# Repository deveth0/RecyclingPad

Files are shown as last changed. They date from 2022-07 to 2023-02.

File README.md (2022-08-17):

# Recycling Pad

This repository contains all required files to build a `Recycling Pad` which is a plugin extension for the [Keygem Switch Tester](https://keygem.store/collections/switch-testers/products/switch-tester-3x3).

It features 3x3 keys, whereby any of the upper three once can be replaced by EC11 encoder(s).

## Gallery

[Fancy Images by @Xibaris](https://imgur.com/a/etkFRNU)

v0.1 revision Board
v0.1 revision PCB rear
v0.1 revision PCB front
v0.1 revision Side

## Required Parts

* 1x PCB
* 1x Pro Micro Controller
* 9x 1n4148 Diode (thru hole)
* 1x 6mm tactile switch (to reset MCU)
* up to 3 EC11 Encoders
* up to 9 Cherry-style mechanical switches
* up to 18 Millmax Sockets 3305 / 7305 (recommended, for hotswap)
* 4x 3.5mm Spacer (3d Print file available) => [Spacer 3.5mm](./Case/Recycling_Pad-Spacer_3,5mm.stl)
* 4x 6mm Spacer (3d Print file available) => [Spacer 6mm](./Case/Recycling_Pad-Spacer_9mm.stl)

Depending on your setup, you can replace any number of the upper switches with EC11 rotary encoders.

## Assembly

As the whole PCB is quite tight packed, you need to keep an eye on the soldering order. If you use Millmax Sockets, it's getting easier as you can remove the switches if required.

1. First solder in all the diodes and the reset switch
2. Then add the MillMax Sockets
3. Solder in the center EC11 encoder (if used)
3. Solder in the Pro Micro Headers (NOT THE Controler)
4. Solder in the the remaining EC11 Encoder (use plate as guide to keep the encoder aligned)
5. If not using Millmax: Add all switches to the plate and solder in the switches
5. Add the controller to the Headers

Depending on the length of your Headers, you might want to cut them after soldering. Otherwise they might touch the PCB and shortcircuit a switch.

## QMK

The `qmk` folder contains some base configurations for the Pad.

Note: rows and columns are switched, therefor your configuration needs to be rotated 90° (see example configs).

## Acknowledgements

Cherry Switch 3d Model: https://3dwarehouse.sketchup.com/model/81cf92a3e03098a5cc90be332989df6e/Key-switch-Cherry

Kicad Schematics / Footprints: https://github.com/imchipwood/dumbpad/tree/master/combo_oled

Schematics for embedded version: https://github.com/kb-elmo/QEZ

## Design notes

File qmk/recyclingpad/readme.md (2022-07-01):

# RecyclingPad

RecyclingPad 3x3 Macropad with up to three encoders

* Maintainer: [deveth0](https://github.com/deveth0)
* PCB repository: [dumbpad on github](https://github.com/deveth0/RecyclingPad)
  * PCB revisions:
    * v1.x - these revisions have two LEDs for layer indication
      * ['v1x'](v1x/): Default setup for single rotary encoder v0.x PCBs
      * ['v1x_left'](v1x_left/): Same as v1x but with rotary encoder on left side (use as blueprint for other positions)

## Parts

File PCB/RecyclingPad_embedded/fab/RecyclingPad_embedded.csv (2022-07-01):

Comment | Designator | Footprint | LCSC Part #
10uF | C1 | C_0805_2012Metric | C91245
22pF | C2,C3 | C_0805_2012Metric | C1804
0.1uF | C4,C5 | C_0805_2012Metric | C49678
1uF | C6 | C_0805_2012Metric | C28323
DIODEDO-1N4148 | D1,D2,D3,D4,D5,D6,D7,D8,D9 | D_SOD-323 | C2128
Polyfuse_Small | F1 | Fuse_1206_3216Metric | C69688
22 | R1,R2 | R_0805_2012Metric | C17561
10k | R3,R7 | R_0805_2012Metric | C17414
5.1k | R4,R5 | R_0805_2012Metric | C27834
CHERRY-MX-ENCODER | RE_0_1 | CHERRY-MX-ENCODER
CHERRY-MX-ENCODER | RE_3_1,RE_3_2 | CHERRY-MX-ENCODER
SW_Push | RESET1 | SW_SPST_TL3342 | C318884
MOMENTARY-SWITCH-SPST-LED-PTH-CHERRY | S1,S2,S3,S4,S5,S6 | CHERRY-MX
ATmega32U2-AU | U1 | TQFP-32_7x7mm_P0.8mm | C618733
SRV05-4 | U2 | SOT-23-6 | C85364
USB_C_Receptacle_USB2.0 | USB1 | USB_C_Receptacle_HRO_TYPE-C-31-M-12 | C165948
Crystal_GND24_Small | X1 | Crystal_SMD_3225-4Pin_3.2x2.5mm | C13738

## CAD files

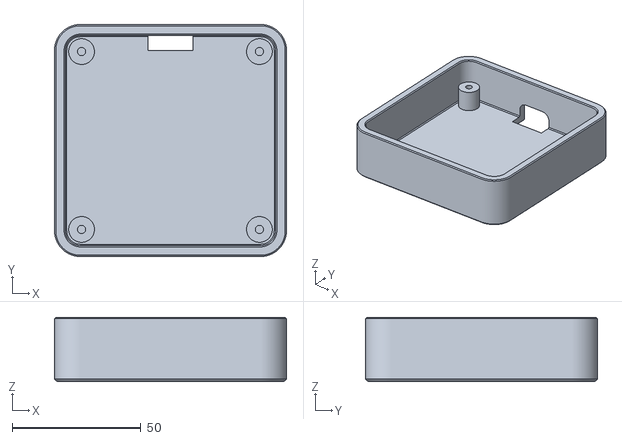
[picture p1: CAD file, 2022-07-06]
Case/Recycling_Pad-Case.stl
90.0 x 90.0 x 25.0

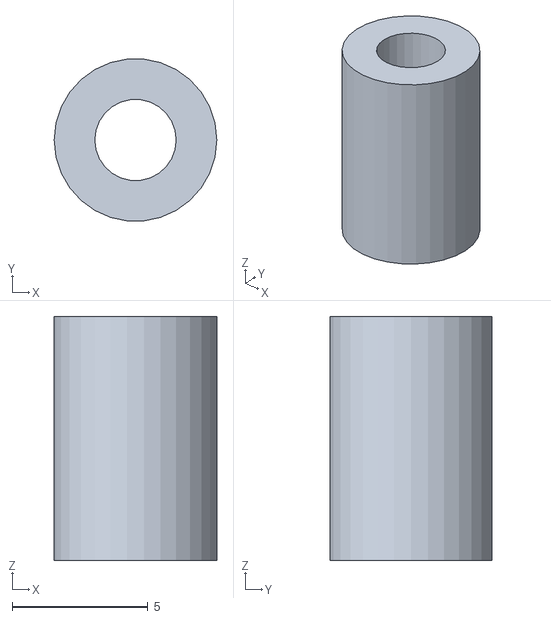
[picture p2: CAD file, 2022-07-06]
Case/Recycling_Pad-Spacer_9mm.stl
6.00 x 5.97 x 9.00

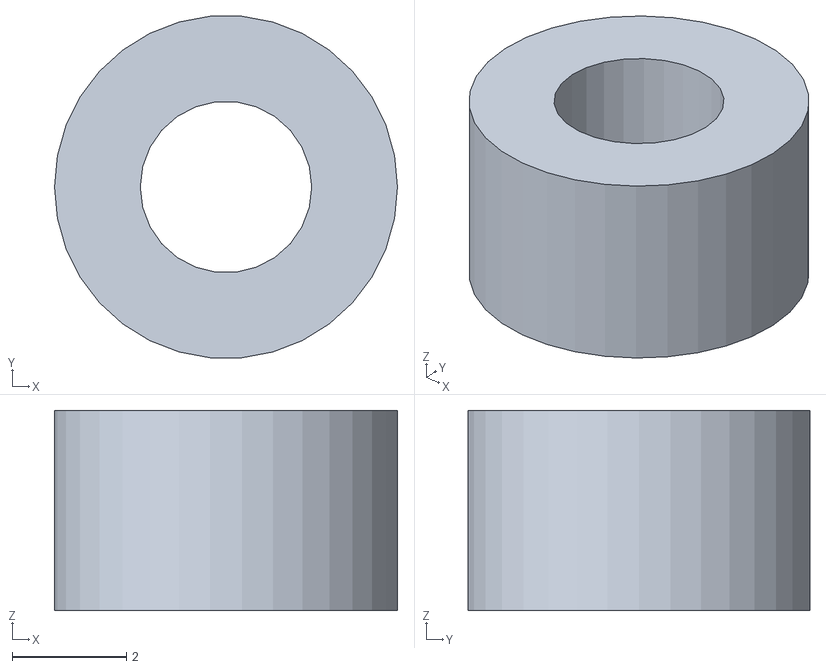
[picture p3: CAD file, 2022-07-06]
Case/Recycling_Pad-Spacer_3,5mm.stl
6.00 x 5.97 x 3.50

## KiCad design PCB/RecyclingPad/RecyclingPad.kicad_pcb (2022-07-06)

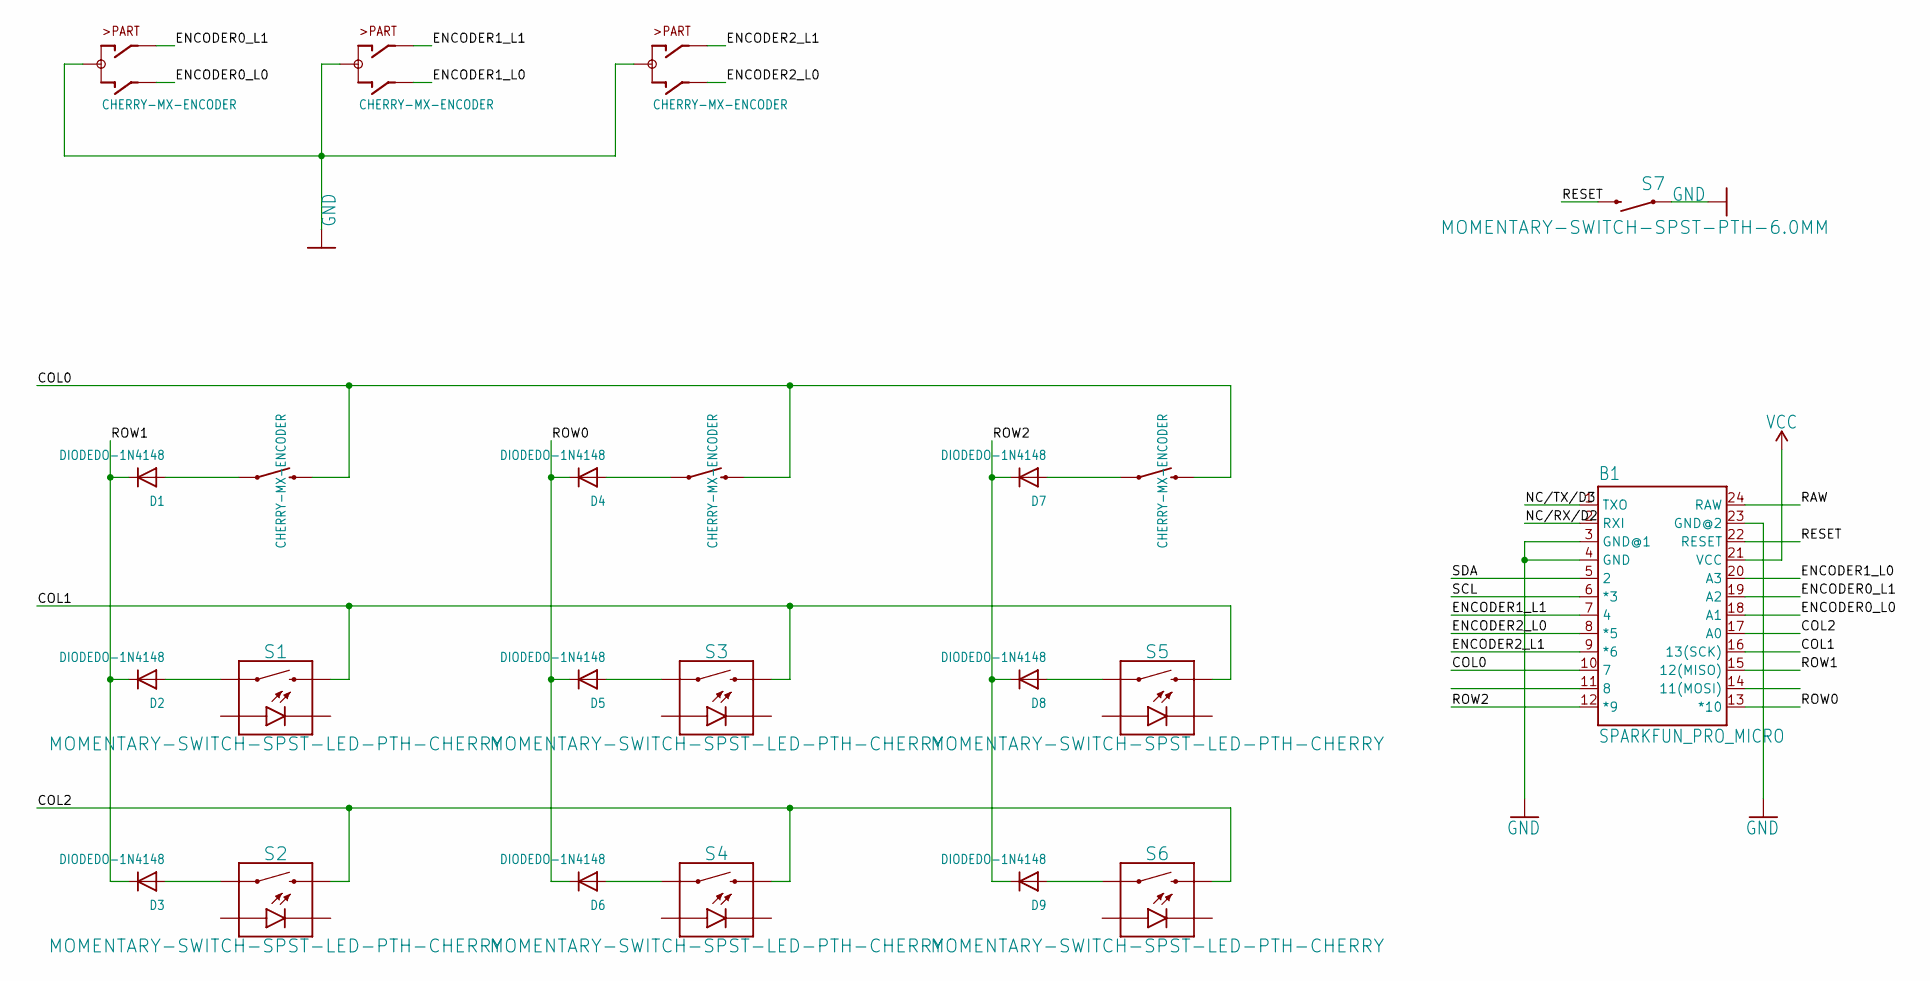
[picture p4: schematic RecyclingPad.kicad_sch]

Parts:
B1: SPARKFUN_PRO_MICRO
D1, D2, D3, D4, D5, D6, D7, D8, D9: DIODEDO-1N4148; DO-1N4148
RE_0_1, RE_3_1, RE_3_2: CHERRY-MX-ENCODER
S1, S2, S3, S4, S5, S6: MOMENTARY-SWITCH-SPST-LED-PTH-CHERRY; CHERRY-MX
S7: MOMENTARY-SWITCH-SPST-PTH-6.0MM; TACTILE_SWITCH_PTH_6.0MM

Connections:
/COL0: B1.10 (7), RE_0_1.E (2), RE_0_1.S2 (2), RE_3_1.E (2), RE_3_1.S2 (2), RE_3_2.E (2), RE_3_2.S2 (2)
/COL1: B1.16 (13(SCK)), S1.S2 (2), S3.S2 (2), S5.S2 (2)
/COL2: B1.17 (A0), S2.S2 (2), S4.S2 (2), S6.S2 (2)
/ENCODER0_L0: B1.18 (A1), RE_3_1.B
/ENCODER0_L1: B1.19 (A2), RE_3_1.A
/ENCODER1_L0: B1.20 (A3), RE_0_1.B
/ENCODER1_L1: B1.7 (4), RE_0_1.A
/ENCODER2_L0: B1.8 (*5), RE_3_2.B
/ENCODER2_L1: B1.9 (*6), RE_3_2.A
/NC/RX/D2: B1.2 (RXI)
/NC/TX/D3: B1.1 (TXO)
/RAW: B1.24 (RAW)
/RESET: B1.22 (RESET), S7.3 (2)
/ROW0: B1.13 (*10), D4.C, D5.C, D6.C
/ROW1: B1.15 (12(MISO)), D1.C, D2.C, D3.C
/ROW2: B1.12 (*9), D7.C, D8.C, D9.C
/SCL: B1.6 (*3)
/SDA: B1.5 (2)
GND: B1.3 (GND@1), B1.4 (GND), B1.23 (GND@2), RE_0_1.C, RE_3_1.C, RE_3_2.C, S7.1
unnamed: D1.A, RE_0_1.D (1), RE_0_1.S1 (1)
unnamed: D2.A, S1.S1 (1)
unnamed: D3.A, S2.S1 (1)
unnamed: D4.A, RE_3_1.D (1), RE_3_1.S1 (1)
unnamed: D5.A, S3.S1 (1)
unnamed: D6.A, S4.S1 (1)
unnamed: D7.A, RE_3_2.D (1), RE_3_2.S1 (1)
unnamed: D8.A, S5.S1 (1)
unnamed: D9.A, S6.S1 (1)
VCC: B1.21 (VCC)

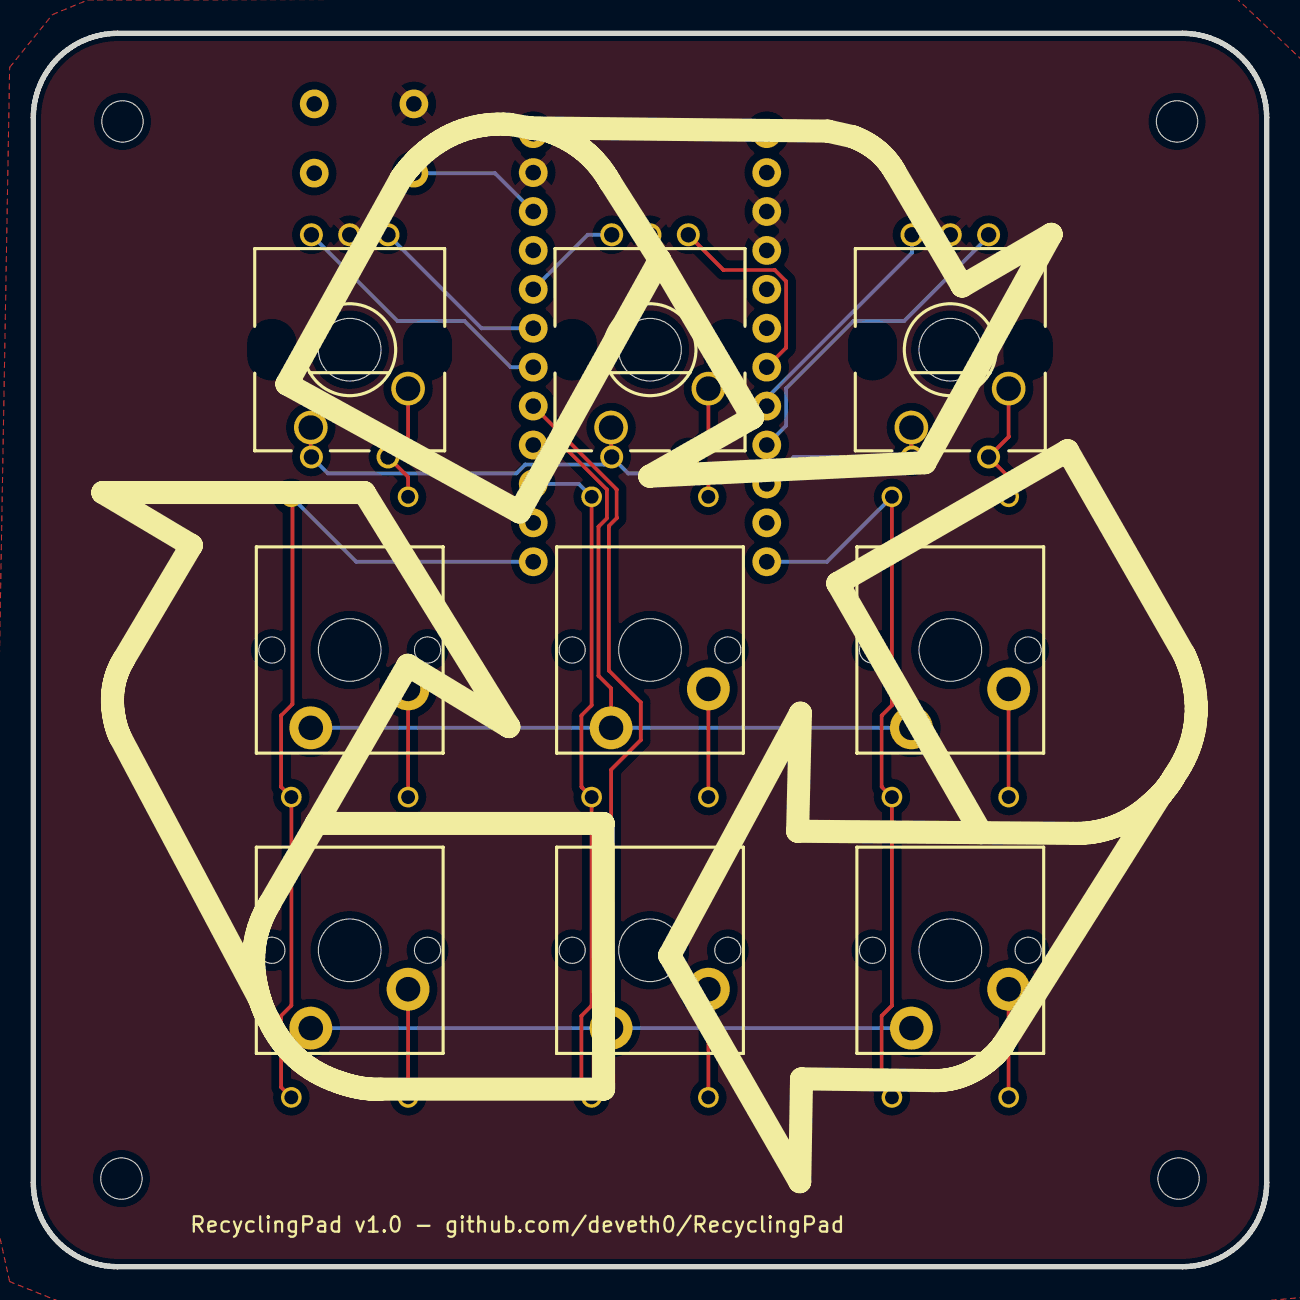
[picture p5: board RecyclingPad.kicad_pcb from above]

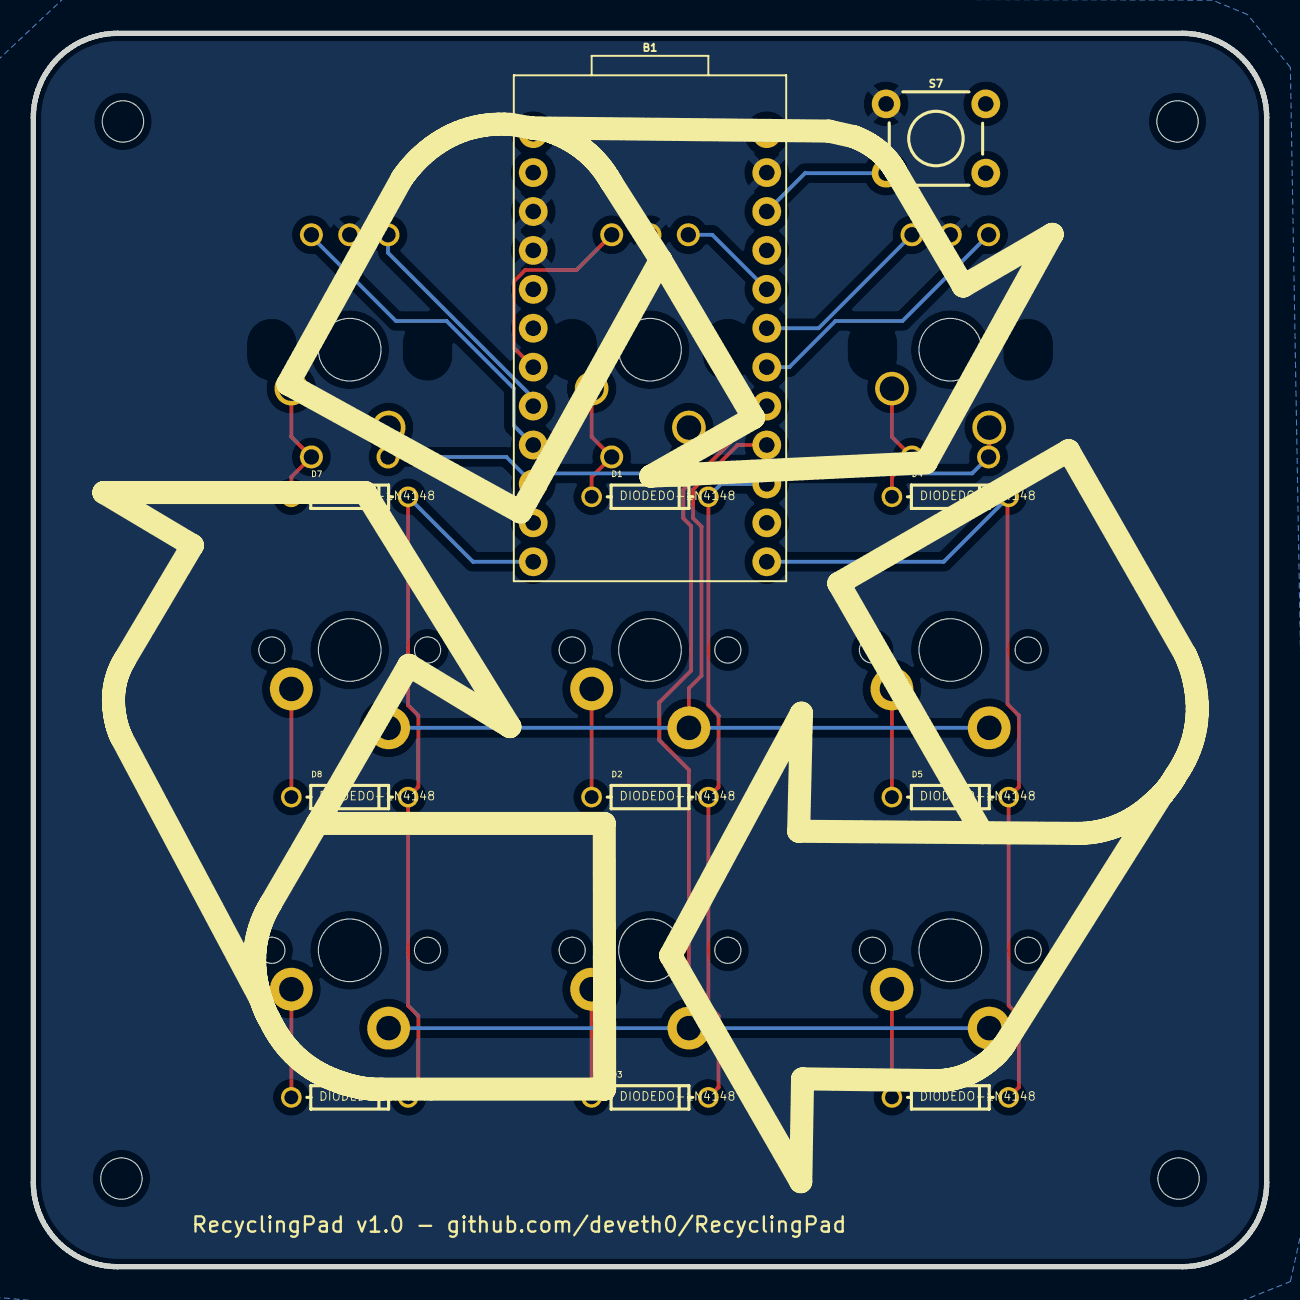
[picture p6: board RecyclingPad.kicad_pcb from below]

Board: 2 copper layers, 80.5 x 80.5 mm, 20 parts (11 on the bottom side), 23 nets.

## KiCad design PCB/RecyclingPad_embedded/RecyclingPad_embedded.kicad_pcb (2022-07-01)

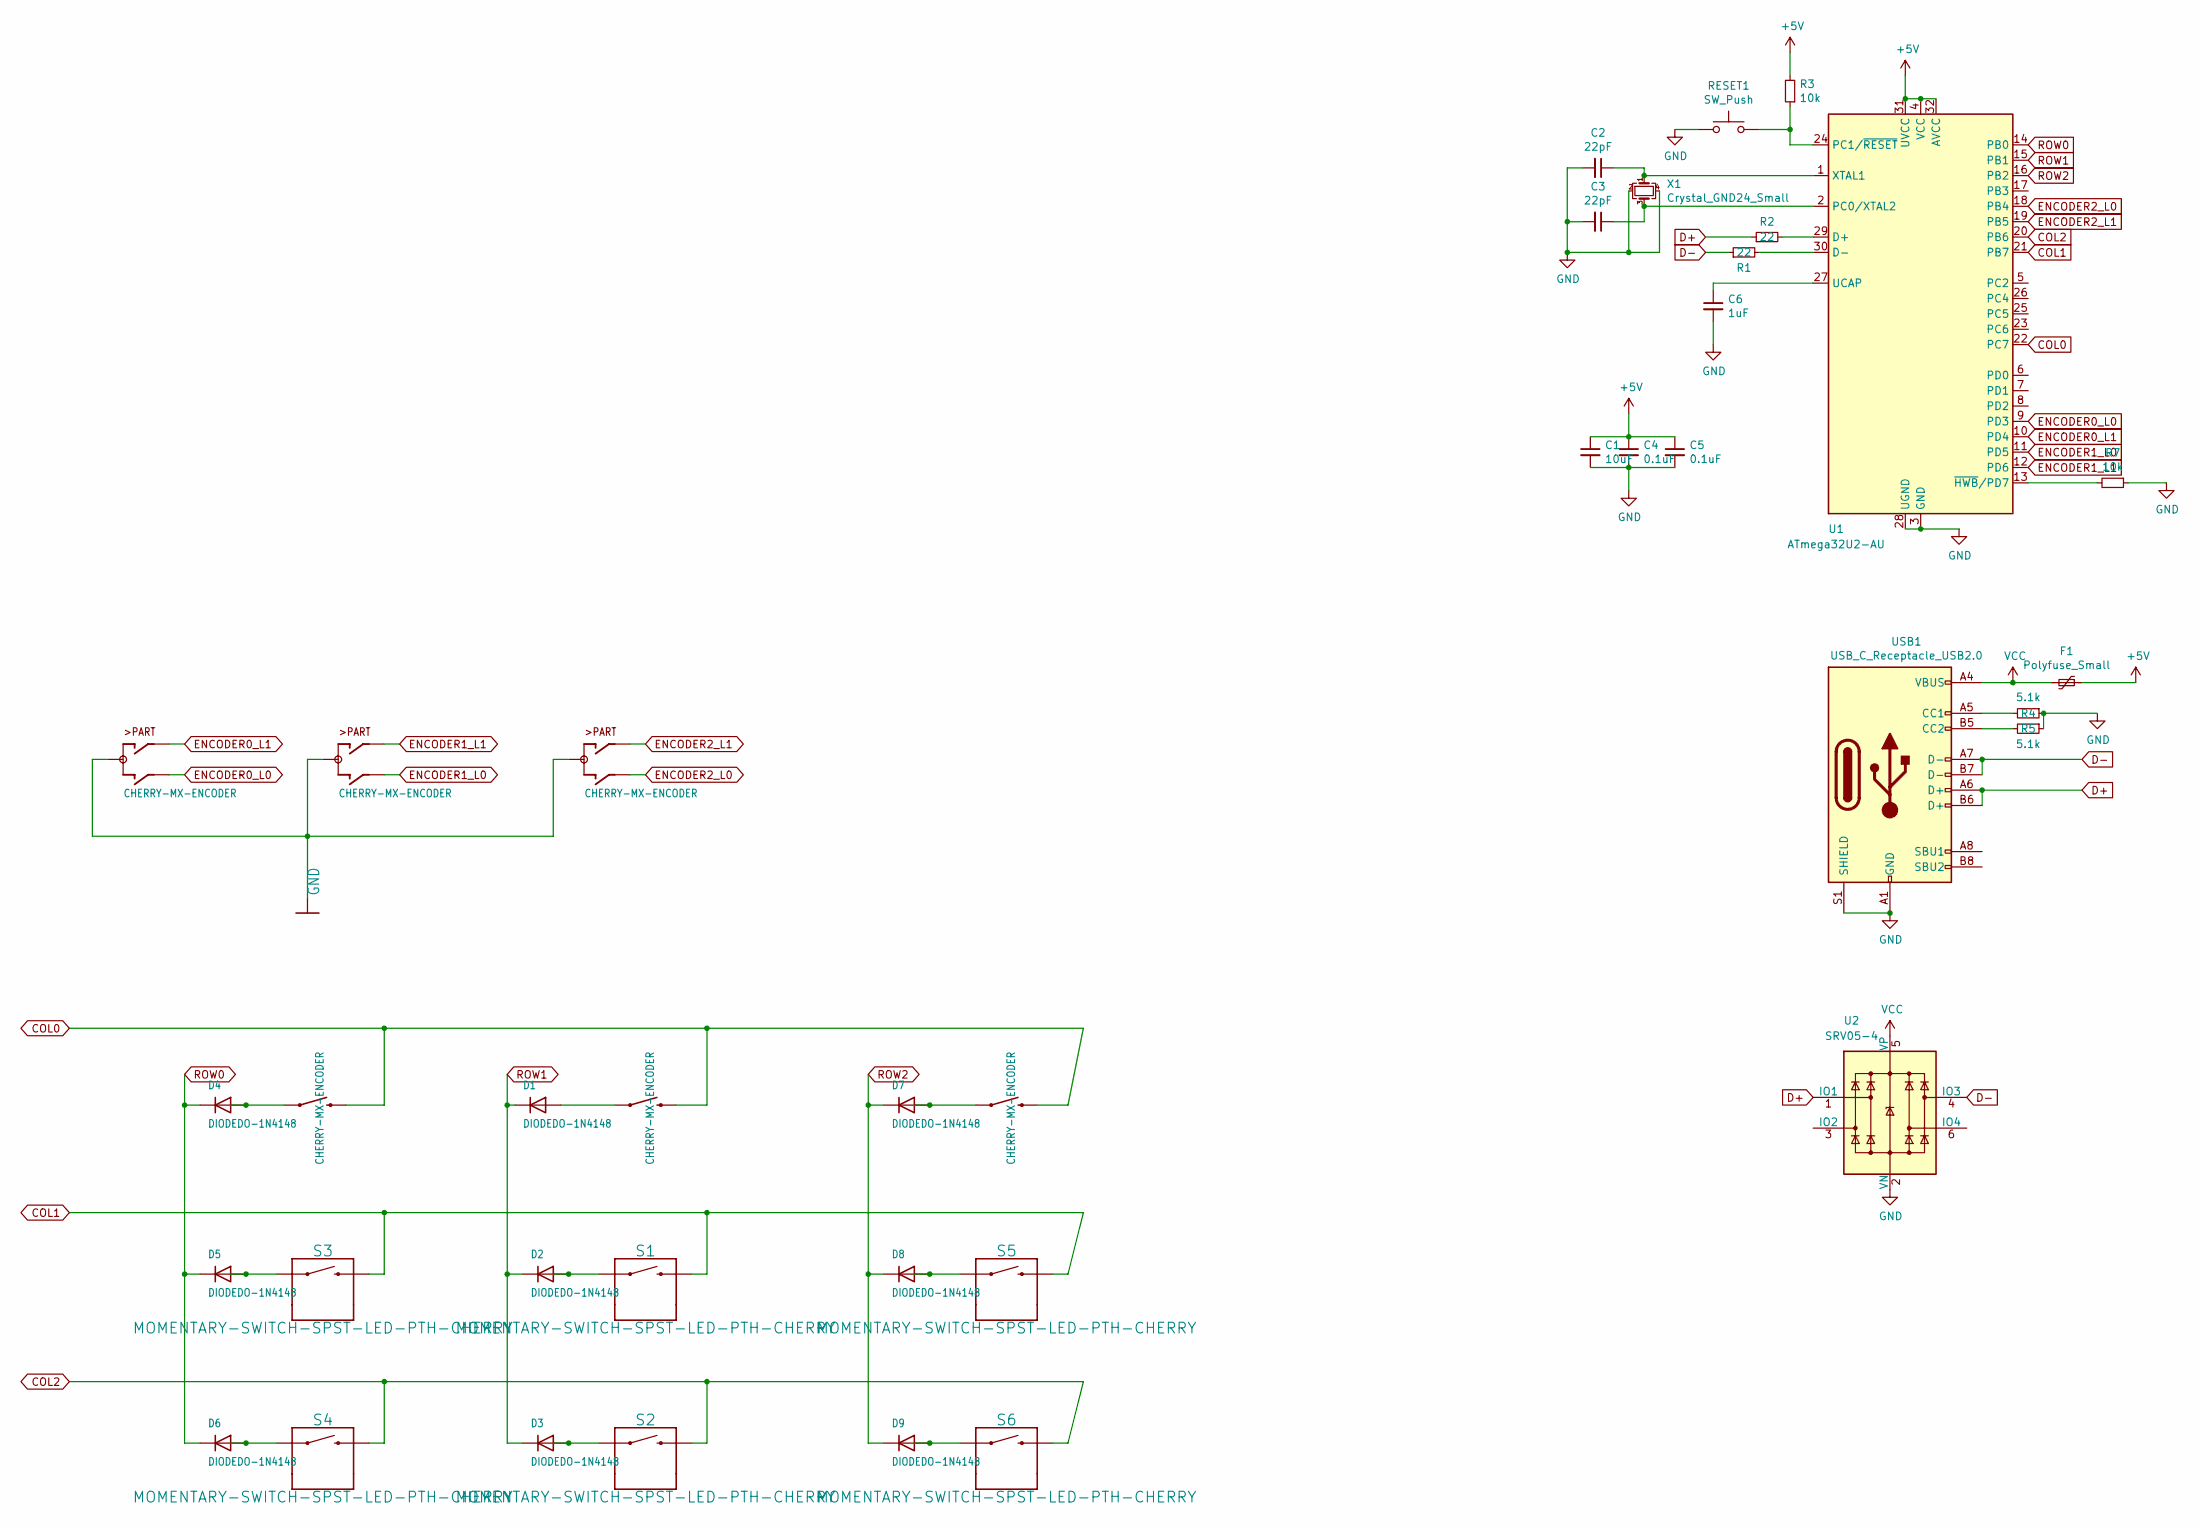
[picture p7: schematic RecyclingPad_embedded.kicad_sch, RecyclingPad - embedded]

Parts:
C1: 10uF; C_0805_2012Metric; LCSC Part C91245
C2, C3: 22pF; C_0805_2012Metric; LCSC Part C1804
C4, C5: 0.1uF; C_0805_2012Metric; LCSC Part C49678
C6: 1uF; C_0805_2012Metric; LCSC Part C28323
D1, D2, D3, D4, D5, D6, D7, D8, D9: DIODEDO-1N4148; D_SOD-323; LCSC Part C2128
F1: Polyfuse_Small; Fuse_1206_3216Metric; LCSC Part C69688
R1, R2: 22; R_0805_2012Metric; LCSC Part C17561
R3, R7: 10k; R_0805_2012Metric; LCSC Part C17414
R4, R5: 5.1k; R_0805_2012Metric; LCSC Part C27834
RESET1: SW_Push; SW_SPST_TL3342; LCSC Part C318884
RE_0_1, RE_3_1, RE_3_2: CHERRY-MX-ENCODER
S1, S2, S3, S4, S5, S6: MOMENTARY-SWITCH-SPST-LED-PTH-CHERRY; CHERRY-MX
U1: ATmega32U2-AU; TQFP-32_7x7mm_P0.8mm; LCSC Part C618733
U2: SRV05-4; SOT-23-6; LCSC Part C85364
USB1: USB_C_Receptacle_USB2.0; USB_C_Receptacle_HRO_TYPE-C-31-M-12; LCSC Part C165948
X1: Crystal_GND24_Small; Crystal_SMD_3225-4Pin_3.2x2.5mm; LCSC Part C13738

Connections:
+5V: C1.1, C4.1, C5.1, F1.1, R3.2, U1.4 (VCC), U1.31 (UVCC), U1.32 (AVCC)
COL0: RE_0_1.E (2), RE_0_1.S2 (2), RE_3_1.E (2), RE_3_1.S2 (2), RE_3_2.E (2), RE_3_2.S2 (2), U1.22 (PC7)
COL1: S1.S2 (2), S3.S2 (2), S5.S2 (2), U1.21 (PB7)
COL2: S2.S2 (2), S4.S2 (2), S6.S2 (2), U1.20 (PB6)
D+: R2.1, U2.1 (IO1), USB1.A6 (D+), USB1.B6 (D+)
D-: R1.1, U2.4 (IO3), USB1.A7 (D-), USB1.B7 (D-)
ENCODER0_L0: RE_3_1.B, U1.9 (PD3)
ENCODER0_L1: RE_3_1.A, U1.10 (PD4)
ENCODER1_L0: RE_0_1.B, U1.11 (PD5)
ENCODER1_L1: RE_0_1.A, U1.12 (PD6)
ENCODER2_L0: RE_3_2.B, U1.18 (PB4)
ENCODER2_L1: RE_3_2.A, U1.19 (PB5)
GND: C1.2, C2.2, C3.2, C4.2, C5.2, C6.2, R4.1, R5.1, R7.1, RESET1.1, RE_0_1.C, RE_3_1.C, RE_3_2.C, U1.3 (GND), U1.28 (UGND), U2.2 (VN), USB1.A1 (GND), USB1.A12 (GND), USB1.B1 (GND), USB1.B12 (GND), USB1.S1 (SHIELD), X1.2, X1.4
unnamed: C2.1, U1.1 (XTAL1), X1.1
unnamed: C3.1, U1.2 (PC0/XTAL2), X1.3
unnamed: C6.1, U1.27 (UCAP)
unnamed: D1.2 (A), RE_0_1.D (1), RE_0_1.S1 (1)
unnamed: D2.2 (A), S1.S1 (1)
unnamed: D3.2 (A), S2.S1 (1)
unnamed: D4.2 (A), RE_3_1.D (1), RE_3_1.S1 (1)
unnamed: D5.2 (A), S3.S1 (1)
unnamed: D6.2 (A), S4.S1 (1)
unnamed: D7.2 (A), RE_3_2.D (1), RE_3_2.S1 (1)
unnamed: D8.2 (A), S5.S1 (1)
unnamed: D9.2 (A), S6.S1 (1)
unnamed: R1.2, U1.30 (D-)
unnamed: R2.2, U1.29 (D+)
unnamed: R3.1, RESET1.2, U1.24 (PC1/~RESET)
unnamed: R4.2, USB1.A5 (CC1)
unnamed: R5.2, USB1.B5 (CC2)
unnamed: R7.2, U1.13 (~HWB/PD7)
ROW0: D4.1 (K), D5.1 (K), D6.1 (K), U1.14 (PB0)
ROW1: D1.1 (K), D2.1 (K), D3.1 (K), U1.15 (PB1)
ROW2: D7.1 (K), D8.1 (K), D9.1 (K), U1.16 (PB2)
VCC: F1.2, U2.5 (VP), USB1.A4 (VBUS), USB1.A9 (VBUS), USB1.B4 (VBUS), USB1.B9 (VBUS)

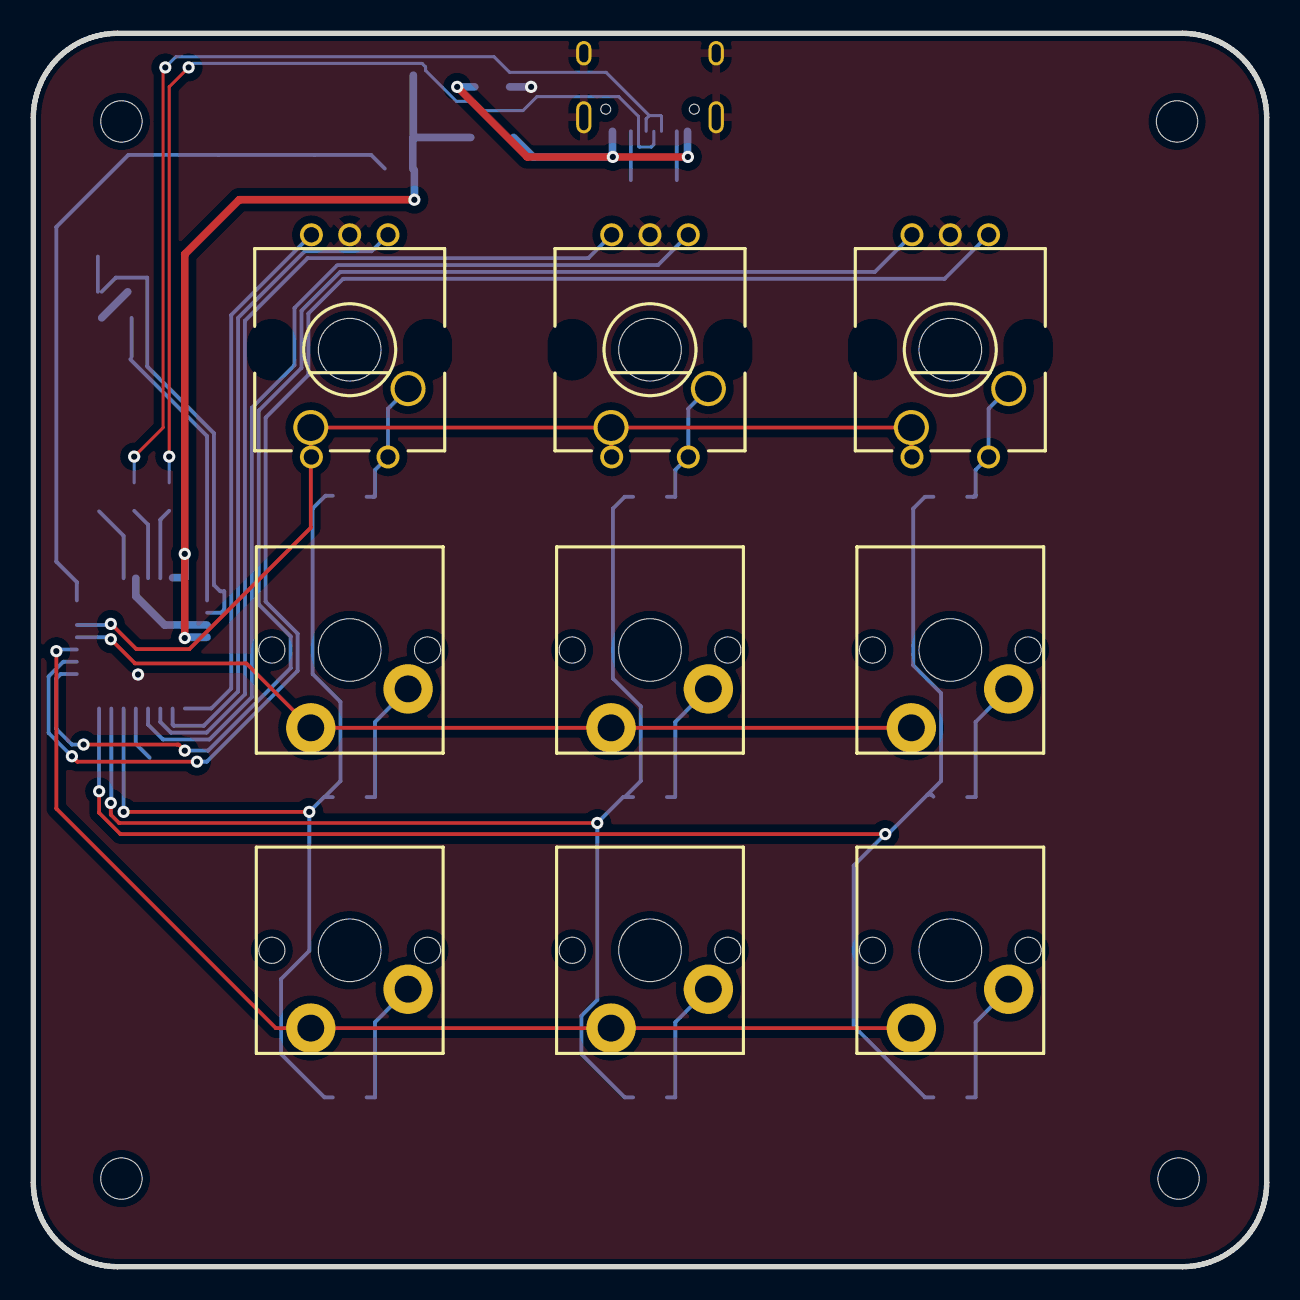
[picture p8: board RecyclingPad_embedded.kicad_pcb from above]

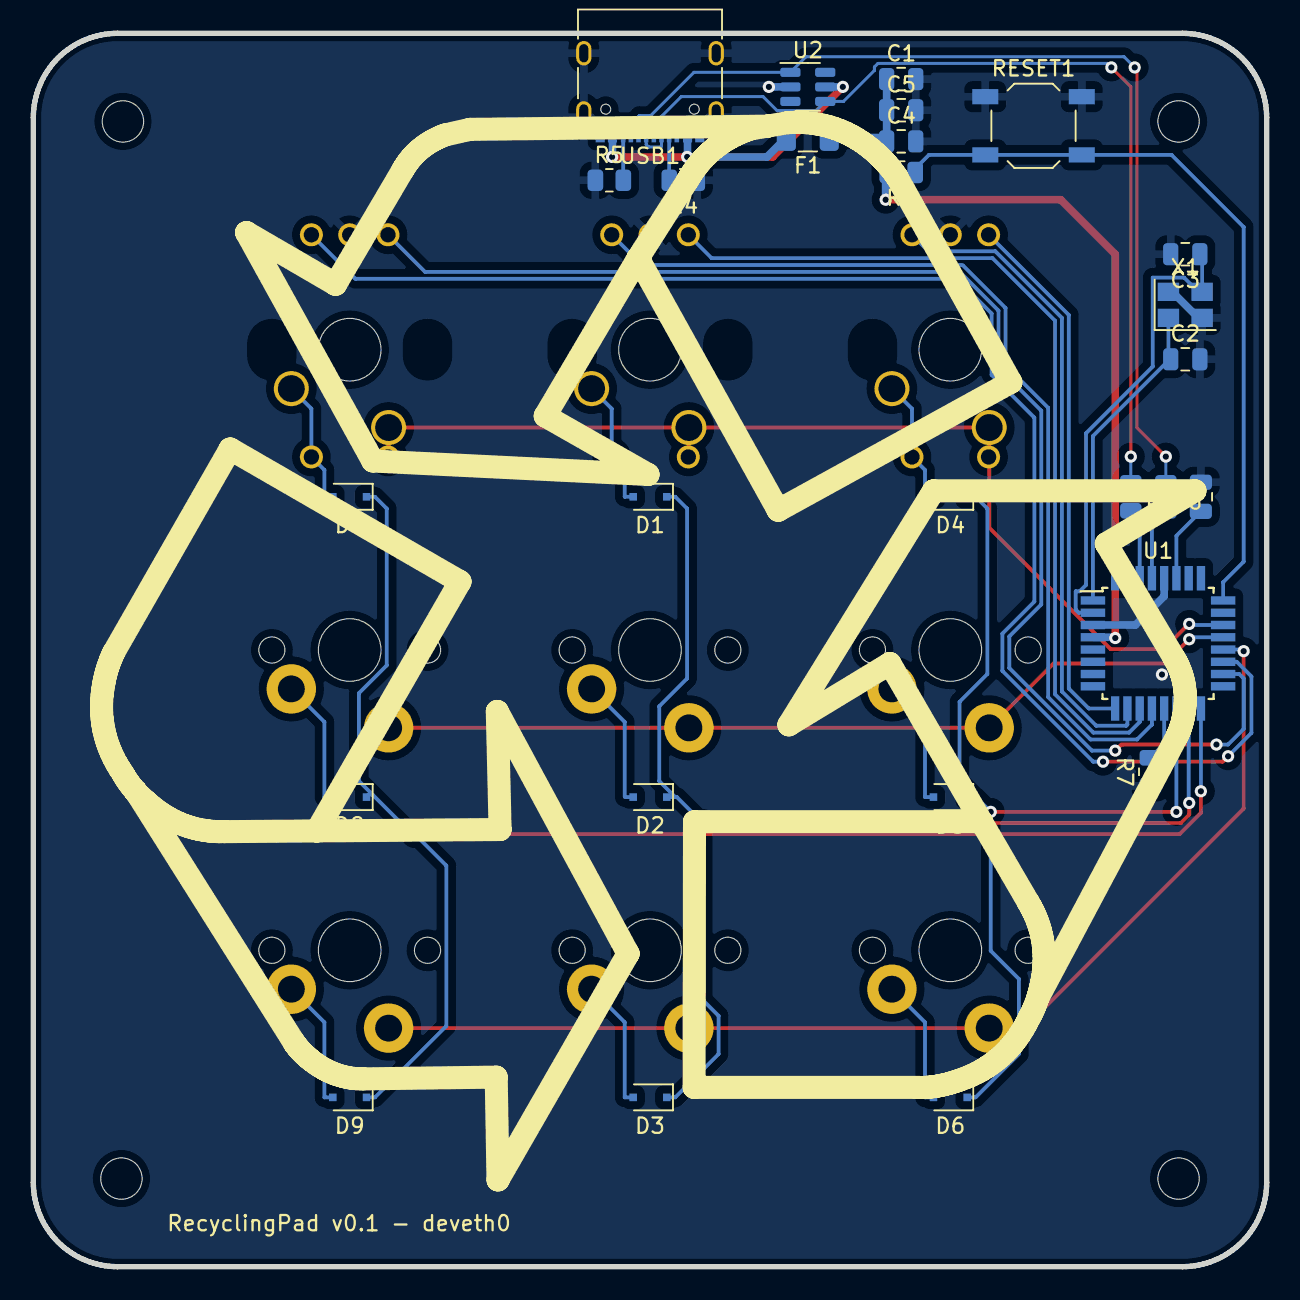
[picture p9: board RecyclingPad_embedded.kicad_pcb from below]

Board: 2 copper layers, 80.5 x 80.5 mm, 36 parts (27 on the bottom side), 35 nets.

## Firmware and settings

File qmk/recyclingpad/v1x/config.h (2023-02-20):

/*
Copyright 2022 imchipwood && deveth0

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
You should have received a copy of the GNU General Public License
along with this program.  If not, see <http://www.gnu.org/licenses/>.
*/
#pragma once

// clang-format off

/* Column/Row IO definitions */
#define MATRIX_ROWS 3
#define MATRIX_COLS 3
#define MATRIX_ROW_PINS { B5, B3, B6 }
#define MATRIX_COL_PINS { F7, B1, E6 }

/*  rotary encoder */
#define ENCODERS_PAD_A { F6, F4, C6 }
#define ENCODERS_PAD_B { F5, D4, D7 }

#define ENCODER_RESOLUTION 2


/* Bootmagic - hold down rotary encoder pushbutton while plugging in to enter bootloader */
#define BOOTMAGIC_LITE_ROW 0
#define BOOTMAGIC_LITE_COLUMN 0

// clang-format on423

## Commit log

2022-06-26 Initial PCB
    [RecyclingPad.kicad_pcb, RecyclingPad.kicad_sch]
2022-07-01 Embedded Version of the Recycling Pad (untested)
    [RecyclingPad.kicad_pcb, RecyclingPad.kicad_sch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]
2022-07-05 Add triple encoder
2022-07-06 Update recyclingPad v1.0
    [RecyclingPad.kicad_pcb, RecyclingPad.kicad_sch, Recycling_Pad-Spacer_3,5mm.stl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]
2022-07-06 Add case printable
    [Recycling_Pad-Case.stl]

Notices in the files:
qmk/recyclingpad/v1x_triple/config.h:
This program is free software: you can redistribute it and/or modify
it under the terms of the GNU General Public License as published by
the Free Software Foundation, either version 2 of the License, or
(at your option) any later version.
